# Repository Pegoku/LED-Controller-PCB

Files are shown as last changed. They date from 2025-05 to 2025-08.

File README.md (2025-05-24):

# LED Controller
A simple monochromatic LED controller for Home Assistant, powered by ESPHome on a XIAO ESP32-C3.

## Features
- Brightness control via Home Assistant UI  
- Over-the-air (OTA) updates  

## Images
<details>
  <summary>Final project</summary>

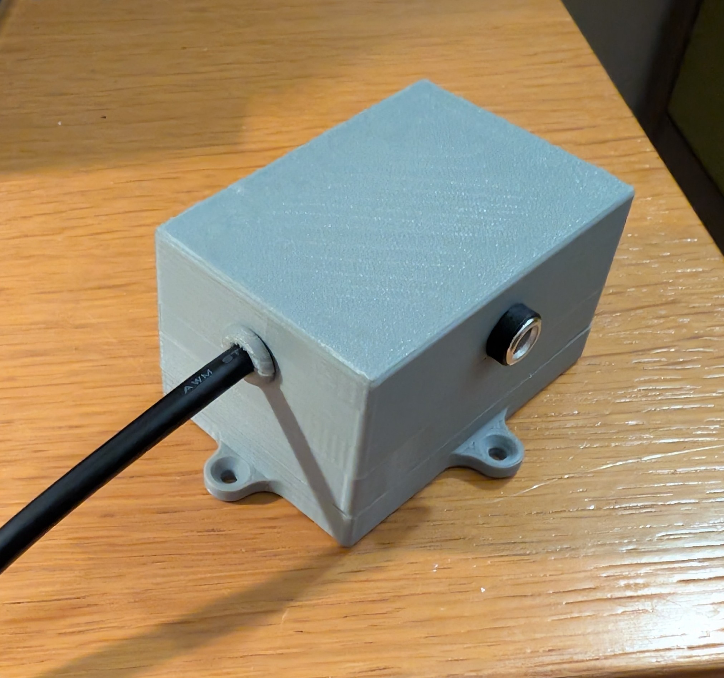
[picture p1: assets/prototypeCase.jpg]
Final
  
</details>
<details>
  <summary>Schematic</summary>

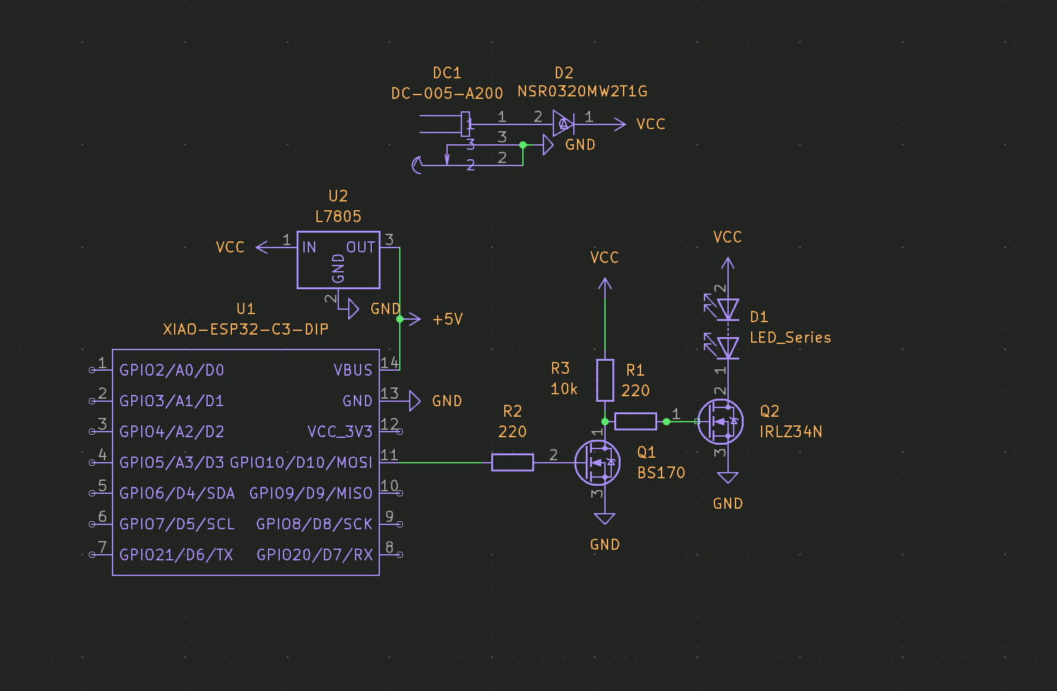
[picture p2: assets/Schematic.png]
schematic
  
</details>
<details>
  <summary>PCB</summary>

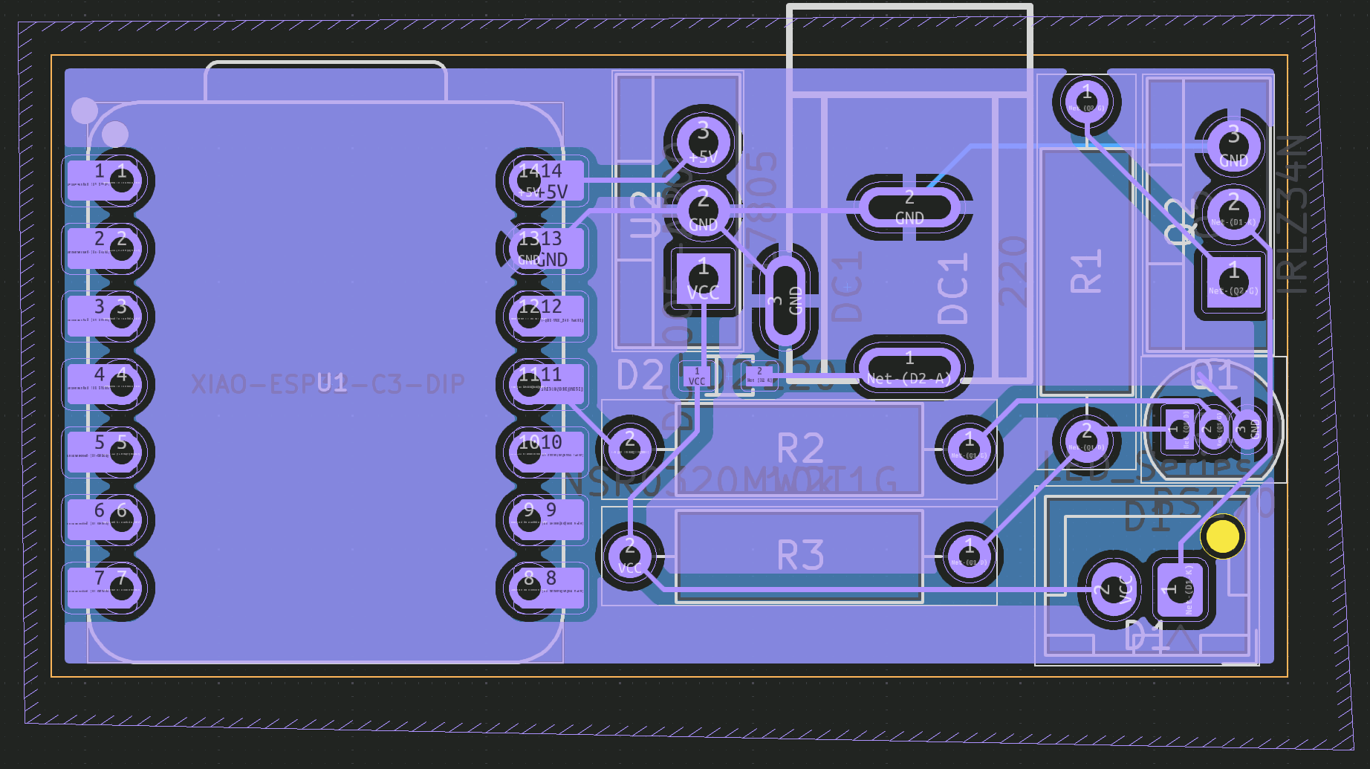
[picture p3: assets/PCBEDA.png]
PCB design
  
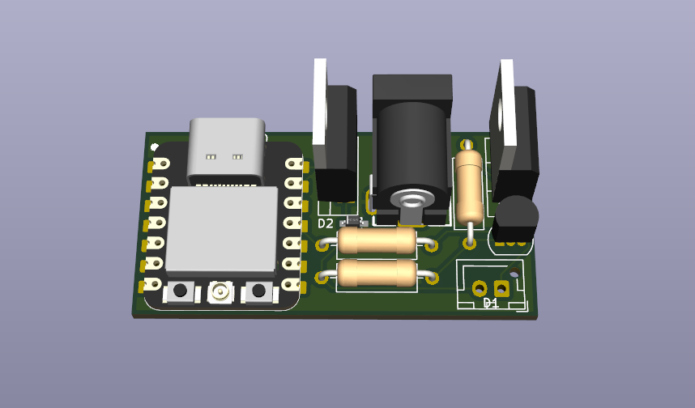
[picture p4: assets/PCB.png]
PCB render
  
</details>

## BOM
| Item Name | What the item is for in your project | Item source | Item price | Total Price |
|---|---|---|---|---|
| JST XH connector | Light connector | https://es.aliexpress.com/item/10050074608978V65.html | 1.22€ | 77.15€ |
| SS2040FL Diode | Reverse polarity protection | https://es.aliexpress.com/item/1005009042615388.html | 5.39€ | 87.75 USD |
| 5.5mm jack | PSU connector | https://es.aliexpress.com/item/10000000716763.html | 1.39€ | |
| BS170 | Driver for power mosfet | https://es.aliexpress.com/item/1005007109406326.html | 1.44€ | |
| IRLZ34N | Power Mosfet | https://es.aliexpress.com/item/1005007174349301.html | 1.90€ | |
| 220 Ω resistor | Mosfet series resistor | https://es.aliexpress.com/item/1005006750101049.html | 1.08€ | |
| 10 kΩ resistor | Pullup resistor | https://es.aliexpress.com/item/1005006750101049.html | 1.08€ | |
| XIAO ESP32C3 | MCU | https://es.aliexpress.com/item/1005006828136326.html | 8.29€ | |
| L7805CV | Regulate 5V | https://es.aliexpress.com/item/1005004989595789.html | 1.69€ | |
| PCB | The main PCB | https://aisler.com/ | 35.67€ | |
| ELEGOO PLA filament | Printing case | https://www.amazon.es/-/en/Filament-Printer-Dimensional-Accuracy-Printers/dp/B0CD77VHBZ | 18€ | |

## Configuration

All firmware configuration lives in [code.yaml](code.yaml):

```yaml
esphome:
  name: led-controller
  friendly_name: LED-Controller

esp32:
  board: esp32-c3-devkitm-1
  framework:
    type: arduino

logger:

api:
  encryption:
    key: "YOUR_API_ENCRYPTION_KEY"

ota:
  - platform: esphome
    password: "YOUR_OTA_PASSWORD"

wifi:
  ssid: !secret wifi_ssid
  password: !secret wifi_password
  ap:
    ssid: "Led-Controller"
    password: "FALLBACK_AP_PASSWORD"

light:
  - platform: monochromatic
    name: "Light Bar"
    output: gpio_light
    id: light_bar1
    icon: "mdi:ceiling-light"

output:
  - platform: ledc
    pin: GPIO10
    id: gpio_light
    inverted: true

captive_portal:
```

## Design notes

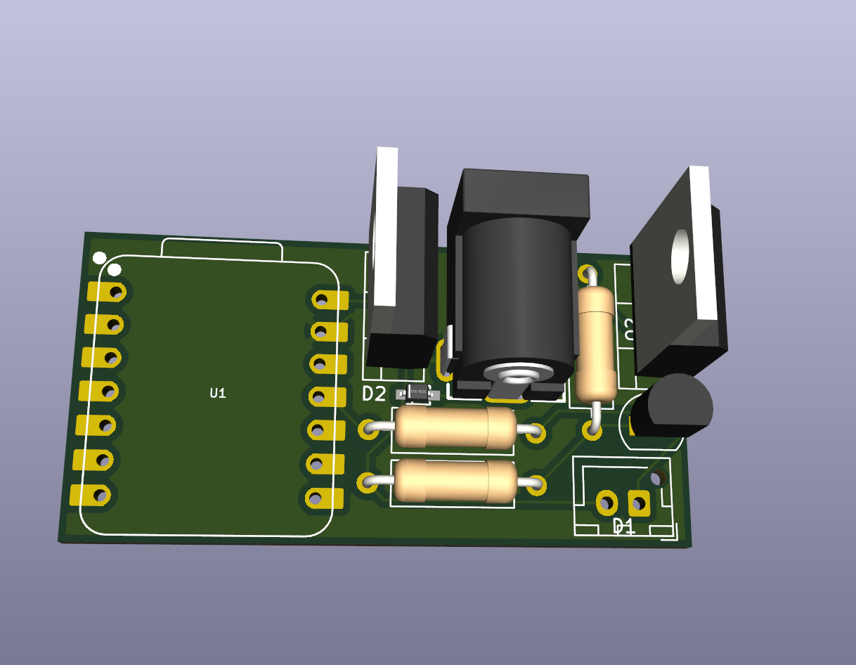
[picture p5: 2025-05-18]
PCB/LEDController/production/Pasted image.png

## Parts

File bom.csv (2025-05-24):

Item Name | What the item is for in your project | Item source | Item price | Total Price
JST XH connector | Light connector | https://es.aliexpress.com/item/1005007460897865.html | 1.22 +IKw- | 77.15 +IKw-
SS2040FL Diode | Reverse polarity protection | https://es.aliexpress.com/item/1005009042615388.html | 5.39 +IKw- | 87.75 USD
5.5mm jack | PSU connector | https://es.aliexpress.com/item/10000000716763.html | 1.39 +IKw-
BS170 | Driver for power mosfet | https://es.aliexpress.com/item/1005007109406326.html | 1.44 +IKw-
IRLZ34N | Power Mosfet | https://es.aliexpress.com/item/1005007174349301.html | 1.90 +IKw-
220+A6k- resistor | Mosfet series resistor | https://es.aliexpress.com/item/1005006750101049.html | 1.08 +IKw-
10k+A6k- resistor | Pullup resistor | https://es.aliexpress.com/item/1005006750101049.html | 1.08 +IKw-
XIAO ESP32C3 | MCU | https://es.aliexpress.com/item/1005006828136326.html | 8.29 +IKw-
L7805CV | Regulate 5V | https://es.aliexpress.com/item/1005004989595789.html | 1.69 +IKw-
PCB | The main PCB | https://aisler.net | 35.67€
ELEGOO PLA filament | Printing case | https://www.amazon.es/-/en/Filament-Printer-Dimensional-Accuracy-Printers/dp/B0CD77VHBZ | 18€

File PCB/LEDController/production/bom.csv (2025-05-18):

Designator | Footprint | Quantity | Value | LCSC Part #
D1 | JST_XH_B2B-XH-AM_1x02_P2.50mm_Vertical | 1 | LED_Series
D2 | SOD-323_L1.8-W1.3-LS2.5-RD | 1 | NSR0320MW2T1G | C48192
DC1 | DC-IN-TH_DC-005-A200 | 1 | DC-005-A200 | C720557
Q1 | TO-92_Inline | 1 | BS170
Q2 | TO-220-3_Vertical | 1 | IRLZ34N
R1, R2 | R_Axial_DIN0309_L9.0mm_D3.2mm_P12.70mm_Horizontal | 2 | 220
R3 | R_Axial_DIN0309_L9.0mm_D3.2mm_P12.70mm_Horizontal | 1 | 10k
U1 | XIAO-ESP32C3-DIP | 1 | XIAO-ESP32-C3-DIP
U2 | TO-220-3_Vertical | 1 | L7805

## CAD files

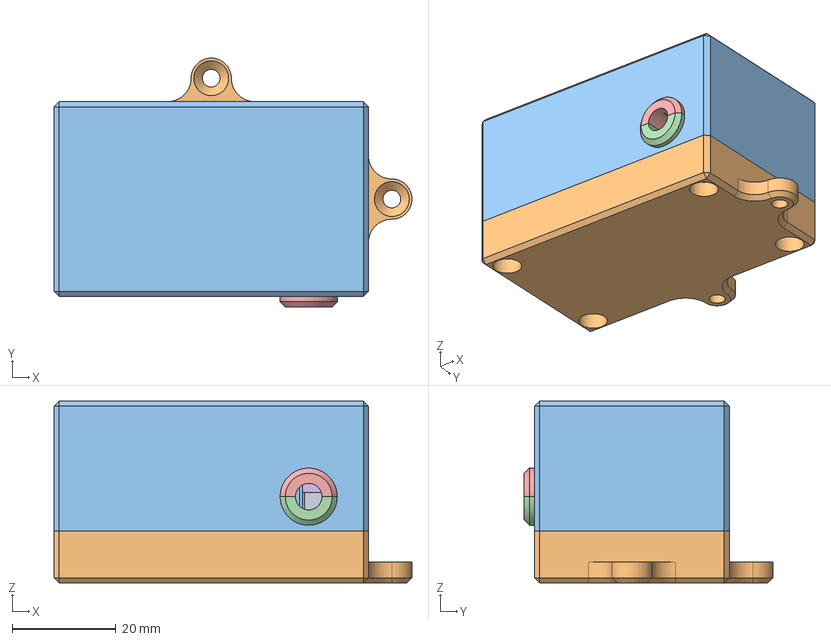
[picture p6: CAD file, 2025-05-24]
Case/Case.FCStd
68.9 x 47.9 x 35.0 mm
TO-92_Inline001
DC-IN-TH_DC-005-A201
R_Axial_DIN0309_L9.0mm_D3.2mm_P12.70mm_Horizontal003
R_Axial_DIN0309_L9.0mm_D3.2mm_P12.70mm_Horizontal004
SOD-323_L1.7-W1.3-H1.1-LS2.006
TO-220-3_Vertical002
TO-220-3_Vertical003
R_Axial_DIN0309_L9.0mm_D3.2mm_P12.70mm_Horizontal005
LightControllerESP32_PCB001
PCB-Base
PCB-Top
Cable-Holder 2
Cable-Holder 1

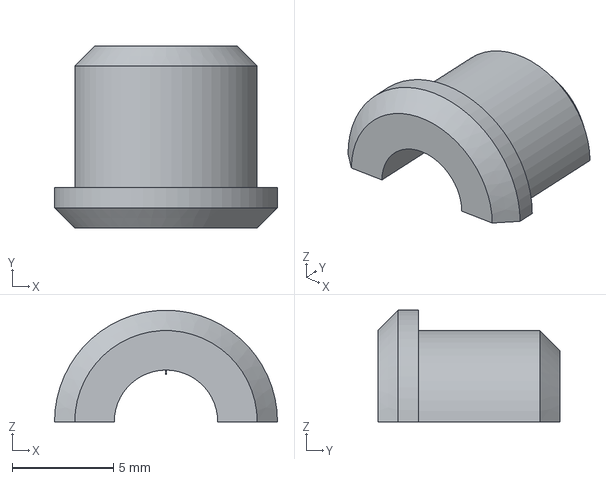
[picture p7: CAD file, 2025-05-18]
Case/Exports/Case-Cable-Holder 2.step
11.0 x 9.00 x 5.50 mm

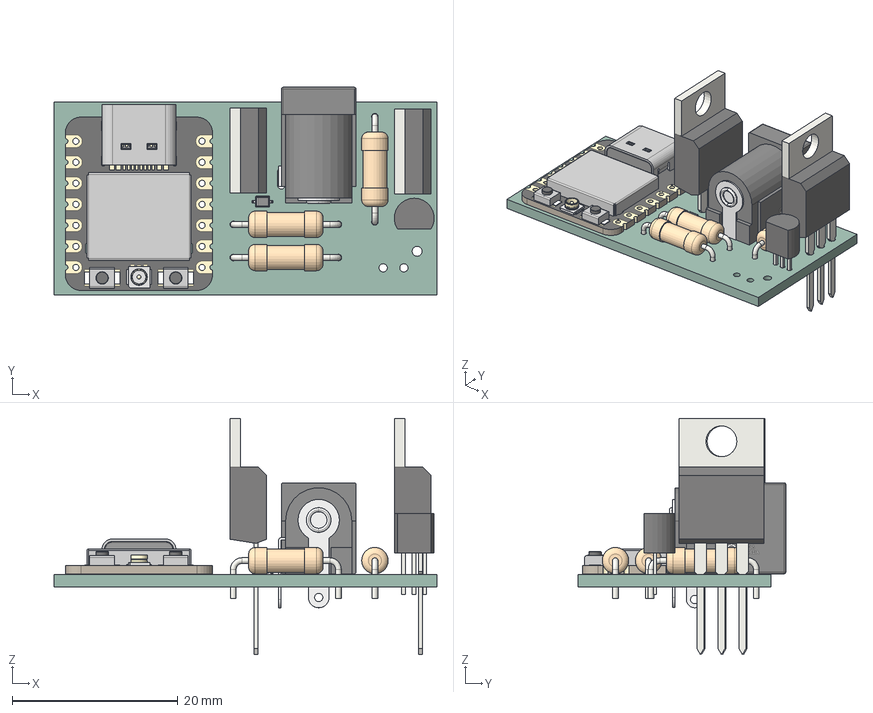
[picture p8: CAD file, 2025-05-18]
PCB/LEDController/LEDController.step
46.2 x 25.1 x 28.5 mm
BOSS-EXTRUDE14_8_
BOSS-EXTRUDE7_4_
BOSS-EXTRUDE7_3_
BOSS-EXTRUDE14_4_
BOSS-EXTRUDE14_2_
BOSS-EXTRUDE14_11_
BOSS-EXTRUDE7_7_
BOSS-EXTRUDE14_9_
BOSS-EXTRUDE14_3_
BOSS-EXTRUDE14_7_
MIRROR2
BOSS-EXTRUDE14_5_
BOSS-EXTRUDE14_12_
BOSS-EXTRUDE7_8_
BOSS-EXTRUDE7_1_
BOSS-EXTRUDE14_10_
BOSS-EXTRUDE7_9_
BOSS-EXTRUDE14_6_
BOSS-EXTRUDE14_1_
BOSS-EXTRUDE7_6_
BOSS-EXTRUDE7_2_
CUT-EXTRUDE5
BOSS-EXTRUDE7_5_
U.FL Connector v1
Button (1) x 2
Shield
TO-92_Inline
DC-IN-TH_DC-005-A200
R_Axial_DIN0309_L9.0mm_D3.2mm_P12.70mm_Horizontal x 3
SOD-323_L1.7-W1.3-H1.1-LS2.5
TO-220-3_Vertical x 2
LightControllerESP32_PCB

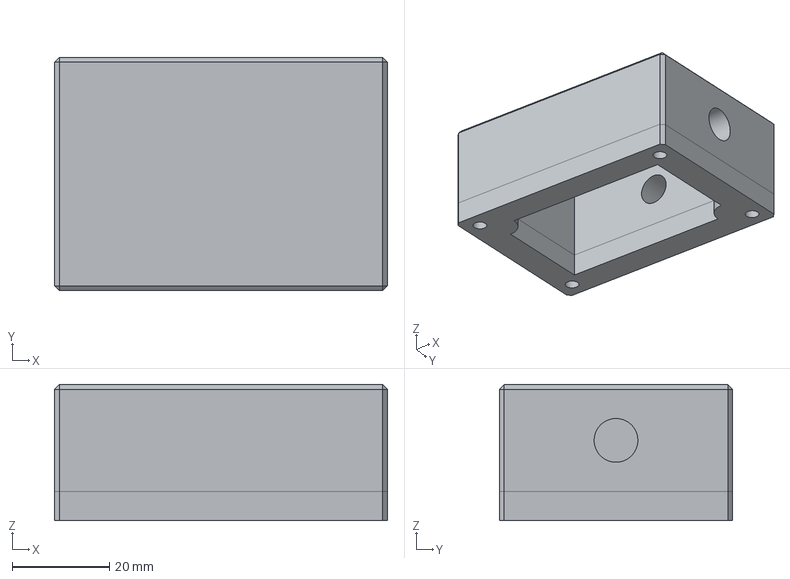
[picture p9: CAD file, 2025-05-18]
Case/Exports/Case-PerfBoard-top.step
68.5 x 48.0 x 28.0 mm

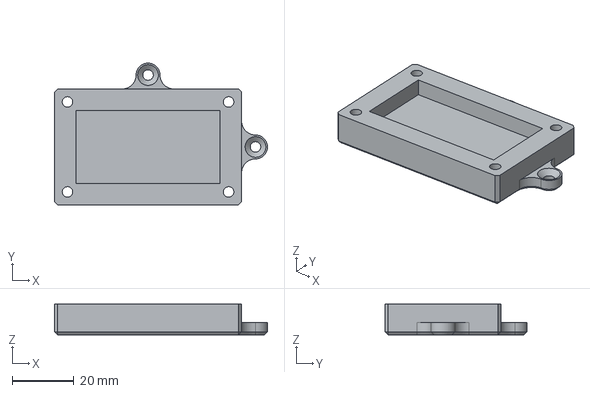
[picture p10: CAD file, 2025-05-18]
Case/Exports/Case-PCB-Base.step
68.9 x 45.9 x 10.0 mm

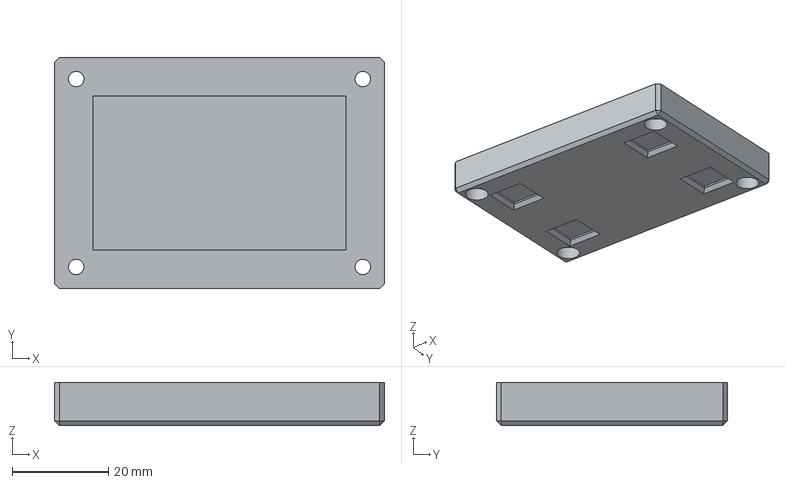
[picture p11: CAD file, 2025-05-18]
Case/Exports/Case-PerfBoard-Base.step
68.5 x 48.0 x 9.00 mm

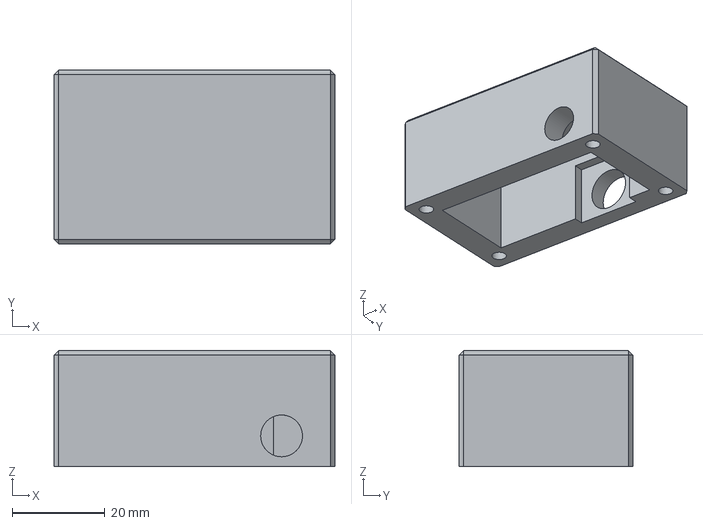
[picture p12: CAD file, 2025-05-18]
Case/Exports/Case-PCB-Top.step
60.5 x 37.5 x 25.0 mm

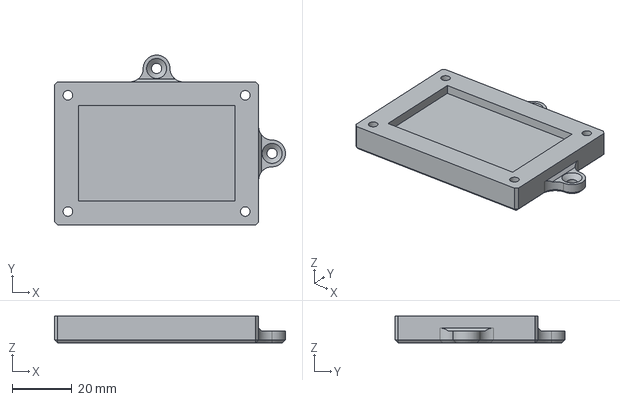
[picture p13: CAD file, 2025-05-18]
Case/Exports/Case-PerfBoard-BaseScrew.step
77.5 x 57.0 x 9.00 mm

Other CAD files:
Case/Exports/Case-Cable-Holder 1.step

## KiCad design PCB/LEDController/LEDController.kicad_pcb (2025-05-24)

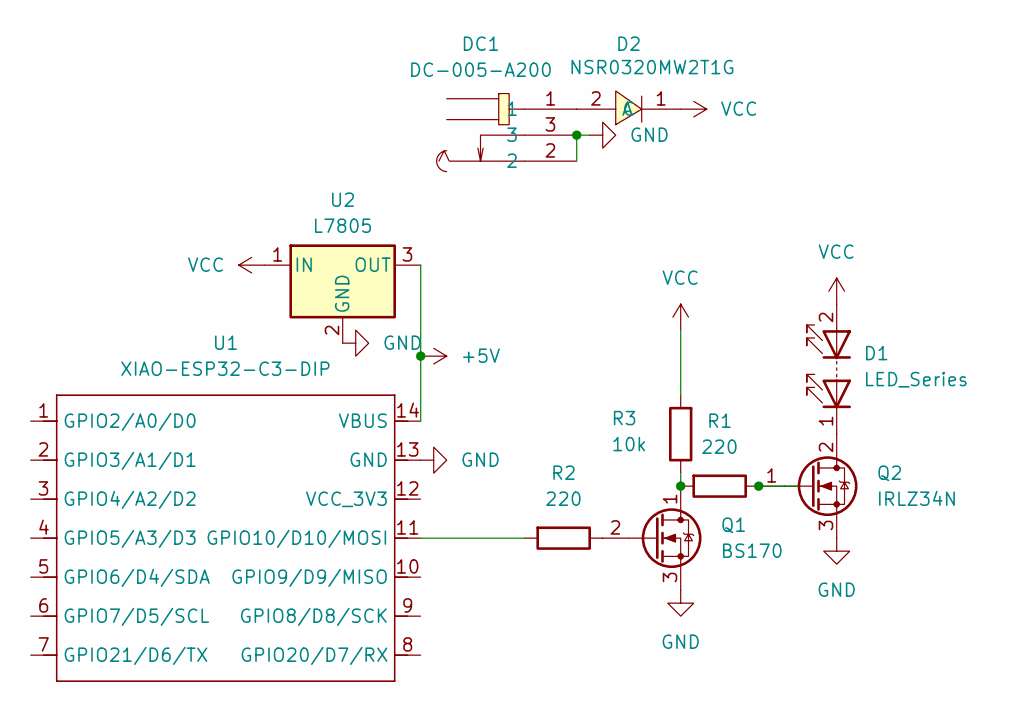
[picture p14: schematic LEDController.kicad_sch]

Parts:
D1: LED_Series; JST_XH_B2B-XH-AM_1x02_P2.50mm_Vertical
D2: NSR0320MW2T1G; SOD-323_L1.8-W1.3-LS2.5-RD; LCSC Part C48192
DC1: DC-005-A200; DC-IN-TH_DC-005-A200; LCSC Part C720557
Q1: BS170; TO-92_Inline
Q2: IRLZ34N; TO-220-3_Vertical
R1, R2: 220; R_Axial_DIN0309_L9.0mm_D3.2mm_P12.70mm_Horizontal
R3: 10k; R_Axial_DIN0309_L9.0mm_D3.2mm_P12.70mm_Horizontal
U1: XIAO-ESP32-C3-DIP; XIAO-ESP32C3-DIP
U2: L7805; TO-220-3_Vertical

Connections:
+5V: U1.14 (VBUS), U2.3 (OUT)
GND: DC1.2, DC1.3, Q1.3 (S), Q2.3 (S), U1.13 (GND), U2.2 (GND)
unnamed: D1.1 (K), Q2.2 (D)
unnamed: D2.2 (A), DC1.1
unnamed: Q1.1 (D), R1.2, R3.1
unnamed: Q1.2 (G), R2.1
unnamed: Q2.1 (G), R1.1
unnamed: R2.2, U1.11 (GPIO10/D10/MOSI)
VCC: D1.2 (A), D2.1 (C), R3.2, U2.1 (IN)

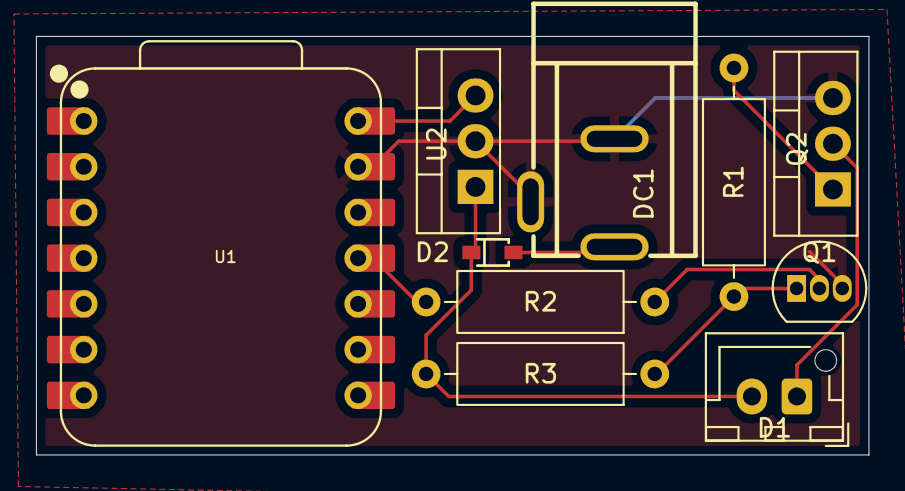
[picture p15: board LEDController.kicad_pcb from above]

Board: 2 copper layers, 46.2 x 23.2 mm, 10 parts (0 on the bottom side), 9 nets.

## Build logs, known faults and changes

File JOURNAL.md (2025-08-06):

---
title: "Led Controller PCB"
author: "Pegoku"
description: "An ESP32-C3 based LED controller PCB for Home Assistant."
created_at: "2025-05-16"
total_time_spent: "23h"
---

# May 16th: Did a protoboard prototype!
I wanted to test if the idea I had would work, so I made a prototype on a protoboard. 
First, I used a XIAO ESP32C3, a few resistors and a Power Mosfet IRLZ34N. The leds didn't completely work, but I found out it was because I wasn't fully saturating the mosfet.
To fix it, I use a BS170 to drive the IRLZ34N. I'm not sure if the BS170 fully saturates. That's why I connected it to 24V (input) so it would saturate the IRLZ34N.
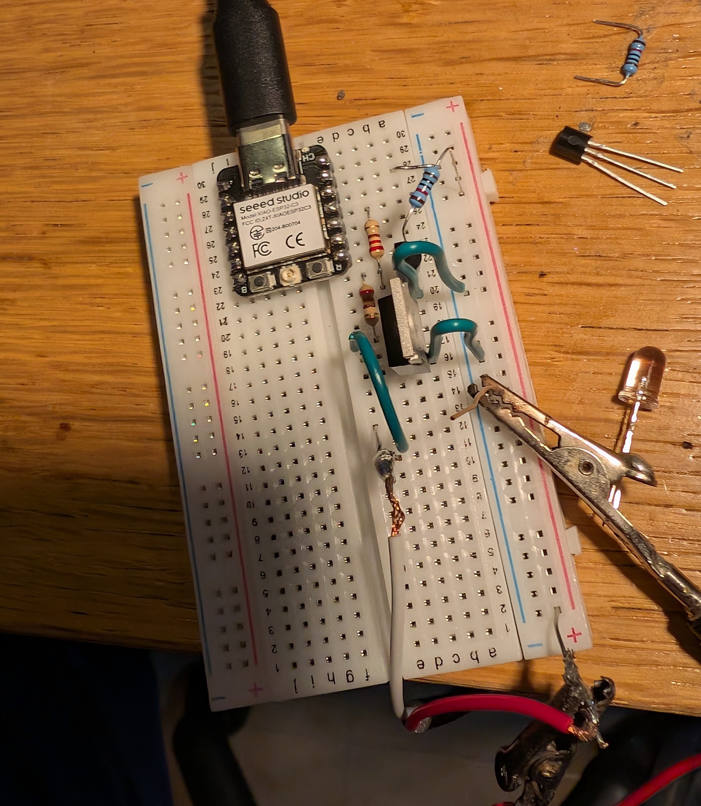
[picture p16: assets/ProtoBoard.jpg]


**Total time spent: 6h**

# May 17th: Convert the design to perfboard
I now had a working prototype, so I wanted to convert it to a perfboard design.
I used KiCad to design the schematic so I would have a better overview of the connections. (I still messed up a few connections, but I fixed them later.)
I added a few extra components, like a 5V regulator so I could power the ESP32C3 from the 24V input, and a few capacitors to filter the power supply.
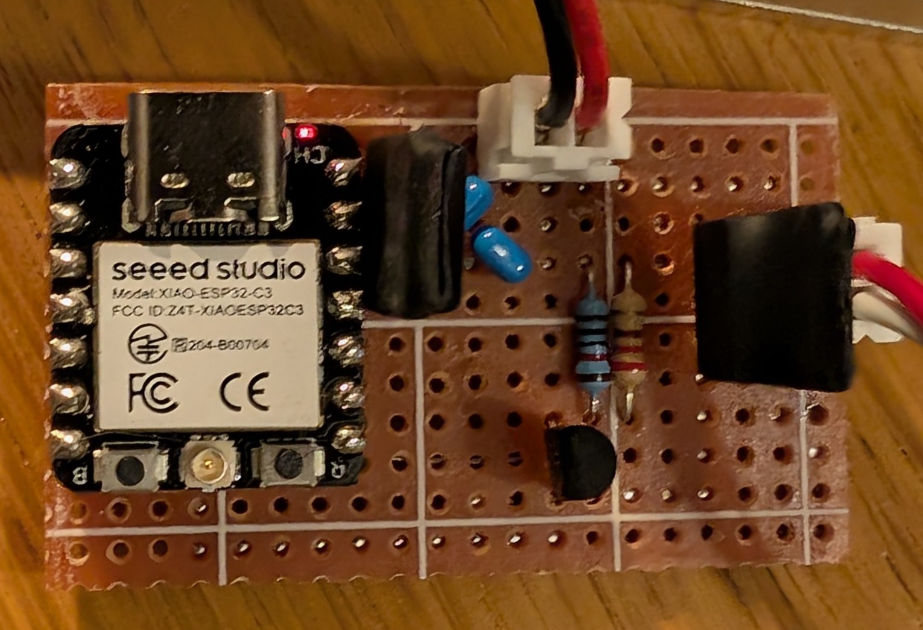
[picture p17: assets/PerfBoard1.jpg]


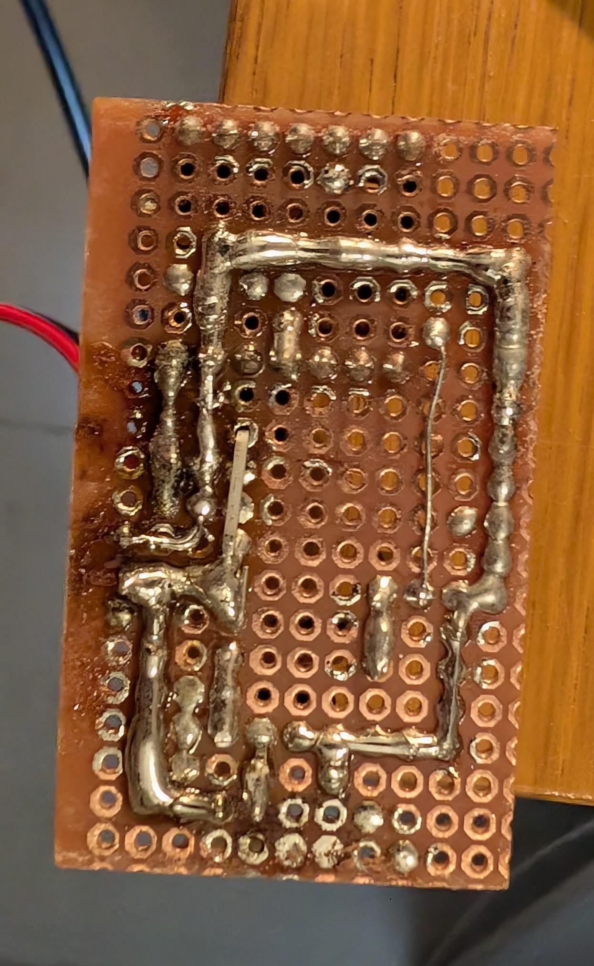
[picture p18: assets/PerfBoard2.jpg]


I also designed a case for the perfboard, so I could start using it.


**Total time spent: 10h**

# May 18th: Did a PCB!
Now I had everything I needed to start my PCB design.
I used KiCad to design the PCB, reusing most of the schematic I used with the perfboard. I did most of the components THT so they would be easier to solder.


I had to also redesign part of the case so it would fit the PCB.
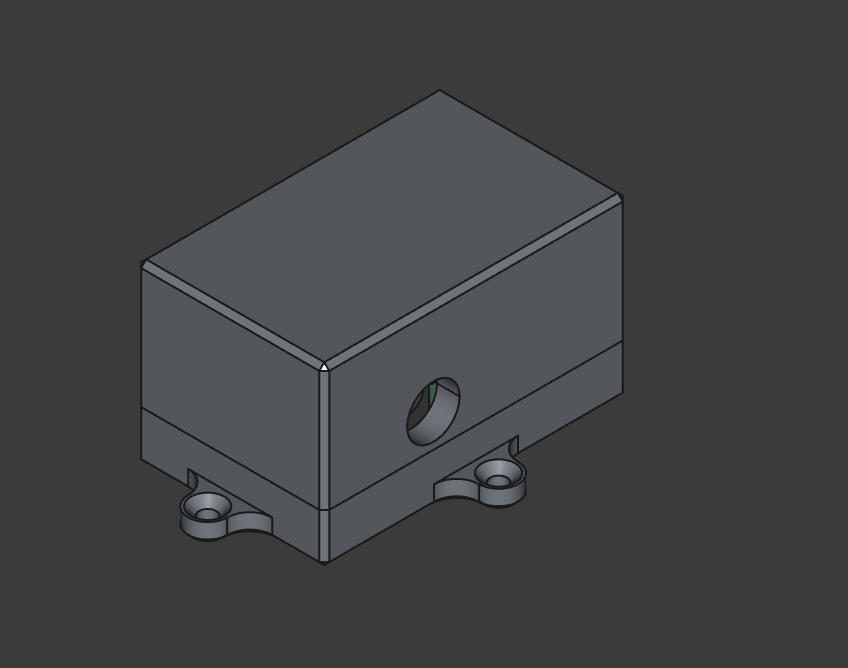
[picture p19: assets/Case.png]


**Total time spent: 6h**

# August 6th: Building the project
Today I built the project. I had to solder the components and assemble the case, but it was quite easy and quick.
I used a 24V power supply I had lying around and connected it to the pcb. 
The only problem I had was that I couldn't find the barrel jack connectors I ordered, so I used a JST one instead.

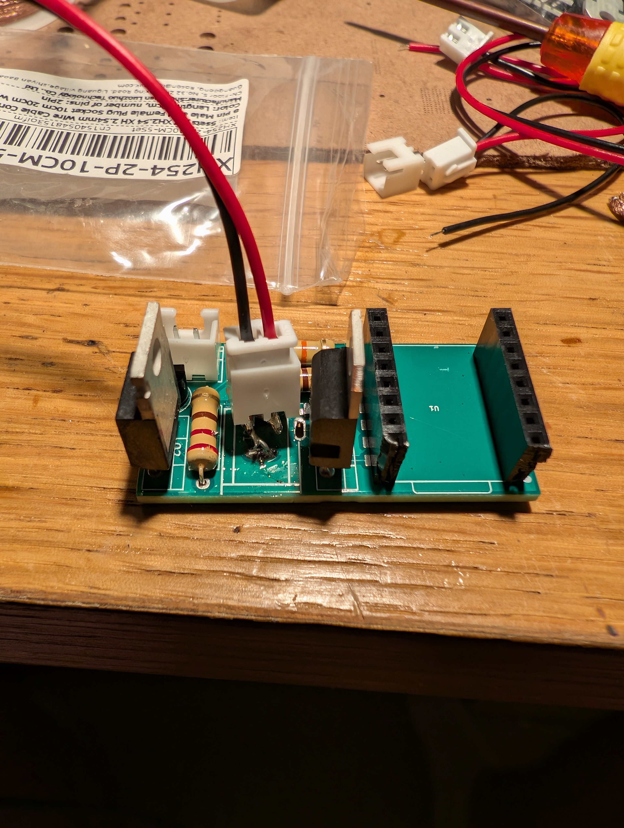
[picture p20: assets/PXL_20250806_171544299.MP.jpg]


**Total time spent: 1h**

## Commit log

2025-05-24 README, BOM and images
    [bom.csv]
2025-05-24 add PCB to BOM
    [LEDController.kicad_pcb, bom.csv]
2025-05-24 add items to BOM
    [bom.csv]
2025-08-06 finish project
    [bom.csv, partitions.csv]
